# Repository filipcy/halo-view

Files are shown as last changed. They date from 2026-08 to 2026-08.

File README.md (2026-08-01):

# HALO View

HALO View is a wall-mounted home interface designed around architecture, not around a tablet.

It transforms a Samsung Galaxy Tab A11 (SM-X130) into a permanent, calm and serviceable element of the interior. Home Assistant is the backend; HALO is the product experience.

## Current status

- Product: HALO View
- Hardware target: Samsung Galaxy Tab A11 SM-X130
- Orientation: portrait
- Hardware stage: Rev A / engineering definition
- Software stage: existing Home Assistant dashboard as MVP

## V1 objective

Mount the tablet without drilling, hide the cable, preserve easy service access and make the device look as if it belonged in the room from the beginning.

## Core principle

> HALO should never look like a tablet mounted on a wall.

## Repository map

- `docs/` — product definition, principles, requirements and decisions
- `cad/` — source models, exports, prototypes and references
- `hardware/` — dock, faceplate, USB routing, materials and BOM
- `ui/` — future HALO interface assets and Home Assistant implementation
- `project/` — epics, user stories and templates
- `manufacturing/` — print and production documentation

Start with [`docs/00_VISION.md`](docs/00_VISION.md).

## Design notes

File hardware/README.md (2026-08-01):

# Hardware

Product-specific engineering documentation:

- `dock/`
- `faceplate/`
- `usb/`
- `materials/`
- `bom/`

CAD source remains under `cad/`; this area stores requirements, selection notes and released hardware documentation.

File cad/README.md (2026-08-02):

# CAD

HALO View mechanical source, review records, and controlled manufacturing exports live here.

## Structure

- `source/` — editable source models and generators
- `reviews/` — iteration review notes and review graphics
- `exports/` — neutral STEP exports
- `stl/` — released print meshes
- `prototypes/` — fit-test and Rev A sections
- `references/` — validated reference geometry

## HALO Dock Rev A

Iteration 2 is generated by [`source/HALO_Dock_Rev_A.py`](source/HALO_Dock_Rev_A.py). It retains the `TabletEnvelope`, split `Faceplate`, `DockBody`, `WallInterface`, and `Assembly` structure, then adds parameter-driven side guides, a lower shelf, non-final upper side-detent studies, and hidden flat mounting fields. The top insertion path stays open. The WallInterface fields physically establish the 1.5 mm shadow gap, and the generator validates the nominal 18 mm wall-to-front stack.

See [`reviews/HALO_Dock_Rev_A_Iteration_2.md`](reviews/HALO_Dock_Rev_A_Iteration_2.md) and its [review schematic](reviews/HALO_Dock_Rev_A_Iteration_2.svg) for scope, exclusions, projection math, and release gates. The [Iteration 1 review](reviews/HALO_Dock_Rev_A_Iteration_1.md) remains the accepted baseline record.

Released files must use controlled part names and revision identifiers. Generator output is a working artifact until its review gates are closed and it is explicitly copied into a release directory.

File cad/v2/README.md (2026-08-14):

# HALO wall mount V2 — design review package

V2 preserves the physically selected Rev A tablet envelope and sliding fit:
125 × 211 × 8 mm, R8.5 corners, 0.20 mm X/Y clearance and 0.30 mm depth
clearance per face. The old 18 mm enclosure stack is replaced by a slim rear
skeleton directly against the wall. The 11 mm dimension is explicitly measured
from the wall-contact plane (Z=0) to the actual front surface of the 8 mm tablet
(Z=3+8), not to a clearance-envelope or printed-retainer face.

The physically validated 8.6 mm Rev A pocket-depth assumption remains recorded
as `VALIDATED_POCKET_DEPTH`, but it is not used as a printable V2 forward
extent. Guides and shelves occupy the real tablet envelope from Z=3.0 to
Z=11.0 mm. The true maximum Z across every generated holder solid is 11.0 mm.

The tablet rear datum remains Z=3.0 mm, but the tablet-facing rear skeleton ends
at Z=2.7 mm. These are deliberately separate concepts: the resulting physical
rear clearance is 0.30 mm without moving the tablet or increasing projection.

The top is open. A split 3 mm bottom shelf carries the tablet; 1.25 mm side lips
prevent forward release while leaving the Samsung bezel dominant. The right
button opening retains its 46 mm span and is moved from 146–192 mm to 124–170 mm
from the bottom datum: exactly 22 mm lower.

The 0.8 mm-thick side retainers occupy Z=10.2–11.0 mm, within the front-most
portion of the tablet thickness envelope. Their front faces are flush with the
actual tablet front at Z=11.0 mm; no retainer material projects in front of it.
Their 1.25 mm XY capture and open-top insertion path are unchanged.

The 22 × 30 mm 90-degree USB-C pocket and 12 mm route are review envelopes, not
a released or production-approved cable fit. Both remain configurable and the
selected adapter, housing and bend radius must be measured before print release.
The route is an opening in the skeleton leading to a wall exit behind
the tablet, so it does not add to global projection.

The camera relief is on the physical **left when the SM-X130 is viewed from the
rear**. Because model X is defined while looking at the front, this is the +X
(right in front view) side. This intentionally fixes the mirrored Rev A relief.

The exposed upper and lower plan edges use a subtle 2 mm chamfer. It is confined
to the exterior outline: the tablet pocket, 0.20 mm side clearance, 1.25 mm
retainers and the Z=11 mm tablet-front plane are unchanged.

## Regenerate

```bash
python3 cad/source/HALO_Wall_Mount_V2.py
```

The command writes the review STL and eight SVG views here. The STL consists of
overlapping closed solids intended to be unioned by the slicer; a native Fusion
rebuild and interference check remain required before manufacturing.

## FDM orientation

Print with the broad rear skeleton on the build plate (wall face down). This
keeps the visible guide walls vertical and avoids supports in the tablet pocket.
Use 0.2 mm layers, at least four perimeters, and bridge the 1.25 mm retention
lips. A brim is preferable to sanding the visible sides.

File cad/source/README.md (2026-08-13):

# HALO Dock Rev A source

`HALO_Dock_Rev_A.py` is the native Fusion 360 parametric source generator. Sprint 3 retains accepted Iteration 2 full-part geometry and adds test coupons, measured Dual Lock recess logic, and gated exports. Static Python checks are not native CAD validation.

## Native validation setup and rerun safety

Every validation run must start in a **fresh, empty Hybrid Design** document. The generator creates multiple internal components, which Fusion does not permit in a Part Design document. If Fusion reports that Part Design documents can contain only one component, open or convert the document to Hybrid Design and begin again in a fresh empty document.

A failed run can leave partial generated components behind. The generator is not transactional and deliberately does not delete existing components, because they may be unrelated user work. Do not rerun it in the document left by a failed validation; discard that document and repeat the validation in another fresh empty Hybrid Design.

## Export modes

`EXPORT_MODE` defaults to `COUPONS_ONLY` and writes controlled STEP + STL pairs for coupon parts to `~/Documents/HALO_Dock_Rev_A/coupons/`. It never exports full Faceplate/DockBody meshes or assembly F3D/STEP/PNG. The 0.2/0.3/0.4 mm clearance gauges, open L corner/lip coupon, and full-pocket-width guide/shelf coupon are included. The separately named left and right single-field wall articles are included only after a valid physical Dual Lock measurement; no STL contains loose wall-coupon bodies.

`FULL_SIZE_PRINT_CANDIDATE` writes to `~/Documents/HALO_Dock_Rev_A/print-candidate/`, but only after the measured wall stack and every explicit evidence flag passes. Flags cover native execution, +1 mm rebuild, interference checks, coupon approval, clearance selection, slicer review, and written authorization. Full parts remain `PRINT CANDIDATE ONLY`. Full mode emits separate component-scoped STEP + STL pairs for Faceplate and DockBody; it never exports the contaminated design root.

The generator finishes each full-size printable component with native Fusion
Combine/Join features. Full-size release validation blocks export unless both
`Faceplate.bRepBodies.count` and `DockBody.bRepBodies.count` equal exactly one.
After changing or pulling this generator, rerun it natively in Fusion 360 from a
fresh, empty Hybrid Design document and repeat the timeline, interference, STEP,
STL, and slicer inspections; static tests cannot prove native BRep joins.

## Measurement blocker

`dual_lock_measured_engaged_thickness` defaults to `0 mm`, meaning **NOT MEASURED**. It is labeled `REQUIRED PHYSICAL MEASUREMENT — exact selected Dual Lock pair`. Do not substitute a catalog claim or estimate. The wall coupon and all full-size exports remain blocked until the exact selected, mated pair is measured and the derived recess leaves positive structural backing.

Follow `cad/reviews/HALO_Dock_Rev_A_Sprint_3.md`. No Fusion execution, export, slicer review, or physical validation was performed in this repository environment.

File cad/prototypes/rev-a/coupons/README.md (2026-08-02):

# Rev A coupon artifacts

This directory is a controlled landing area, **not a release**. The source of the geometry is `cad/source/HALO_Dock_Rev_A.py`. Do not add hand-made or renamed CAD/mesh/image files.

Artifact states are sequential:

1. **source generator** — committed Python only;
2. **generated, unverified** — produced by a native Fusion run but not accepted;
3. **native-verified** — rebuild, symmetry, section, and interference checks recorded;
4. **slicer-verified** — opened at 100%, dimensions/orientation/walls/supports/manifold/build volume checked;
5. **released coupon** — written approval links the evidence and exact file checksum.

Only verified native exports may be placed here. No artifact is currently committed or released.

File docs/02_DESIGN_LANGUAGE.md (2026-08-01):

# Design Language

## Character

HALO is calm, architectural, precise and unobtrusive. It should feel closer to a built-in control panel than to consumer electronics attached after construction.

## Physical language

- Portrait orientation follows the vertical rhythm of the hallway: doors, mirror, tiles and wooden slats.
- Outer corner geometry should visually continue the Samsung tablet rather than surround it with a separate decorative frame.
- The faceplate should be visually thin, with softened or chamfered visible edges.
- A controlled shadow gap should make the product feel light without appearing detached from the wall.
- Visible screws, brackets and adhesive edges are not acceptable.
- The V1 finish is matte black or very dark charcoal, compatible with the existing black interior details.

## Digital language — future direction

- The interface belongs to the room, not to Android or Home Assistant.
- Use restrained colour; colour communicates state or required attention.
- Prefer clear outcomes and actions over raw sensor values.
- Motion should be subtle, direct and without decorative bounce.
- The screen should spend more time quiet or asleep than demanding attention.

## Tone of voice — future direction

Prefer:

- `Dom jest gotowy.`
- `Możesz spokojnie wyjść.`
- `Jedna rzecz wymaga uwagi.`

Avoid:

- technical entity names;
- diagnostic jargon on the primary screen;
- excessive success messages;
- generic smart-home marketing language.

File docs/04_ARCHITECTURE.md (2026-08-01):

# Hardware Architecture

## Components

### HALO Dock

The wall-side structure responsible for:

- adhesive mounting interface;
- structural stiffness;
- alignment;
- cable routing and connector relief;
- controlled wall offset;
- service access.

### HALO Faceplate

The visible product surface responsible for:

- visually integrating the tablet;
- continuing the tablet corner language;
- retaining the tablet without loading the display;
- hiding mechanical interfaces;
- allowing tool-free service access.

### Tablet

Samsung Galaxy Tab A11 SM-X130, bare, portrait orientation. The tablet is not an adhesive mounting surface and should not carry structural loads from the wall interface.

## Assembly concept

```text
Faceplate / carrier
        │
     Tablet
        │
      Dock
        │
  3M Dual Lock
        │
      Tile
```

## Engineering rules

- Model from a central datum and symmetric reference geometry where practical.
- Tablet contact should occur on safe enclosure surfaces, not through pressure on the active display area.
- Allow manufacturing and tablet tolerances; do not use catalogue dimensions as exact fit dimensions without validation.
- Protect the USB-C connector from bending load.
- Hide service openings from normal viewing angles.
- Prefer geometry that prints without visible support damage on exterior surfaces.

## Expansion reserve

V1 may reserve internal routing volume for a future small indicator or ambient-light module. Any reserve must remain invisible, must not increase V1 complexity materially and must not compromise stiffness or printability.

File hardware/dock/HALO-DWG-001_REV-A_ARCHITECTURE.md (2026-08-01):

# HALO-DWG-001 — Dock Rev A Architecture

**Document status:** Design freeze candidate  
**Product:** HALO View  
**Device:** Samsung Galaxy Tab A11 SM-X130  
**Orientation:** Portrait  
**Date:** 2026-08-01

## Purpose

This document freezes the mechanical architecture inputs required to begin the first parametric CAD model. It is not a manufacturing release drawing.

## Product stack

From wall to user:

1. tiled wall;
2. 3M Dual Lock adhesive interface;
3. wall-side Dock;
4. tablet pocket and cable service volume;
5. bare SM-X130 tablet;
6. visible matte Faceplate.

## Accepted Rev A parameters

| Parameter | Rev A value | Release status |
|---|---:|---|
| Tablet orientation | portrait | fixed |
| Tablet insertion direction | from top | fixed |
| Visible bezel | 6.0 mm | fixed |
| Inner screen lip | 0.5 mm target | verify against active display |
| Display recess from Faceplate plane | 0.8 mm | fixed for Rev A |
| Tablet pocket clearance | +0.3 mm per side | prototype assumption |
| Wall shadow gap | 1.5 mm | fixed for Rev A |
| Total projection from tile | approximately 18 mm | packaging target |
| Wall mounting | 3M Dual Lock only | fixed |
| Visible finish | matte black / near-black charcoal | fixed |
| Visible screws | none | fixed |
| Cable exit | bottom, downward | fixed |
| Cable type | standard USB-C envelope preferred | validate during CAD |

## Functional architecture

### Dock

The Dock carries structural loads, provides the wall interface, controls the shadow gap and contains the cable service volume. The adhesive side of the Dual Lock remains attached to the tile during normal tablet service.

### Faceplate

The Faceplate controls the visible geometry, screen recess, edge language and tablet retention. It must not clamp the active glass or require visible fasteners.

### Tablet insertion

The tablet enters from the top, follows side guides and lands on a positive lower datum. Retention must prevent forward movement and rattle while allowing deliberate removal without tools.

### Cable path

The cable connects at the bottom edge near the confirmed 59 mm horizontal datum from the left device edge. The service volume must avoid side-loading the USB-C port and must allow the cable to leave vertically downward. Final chamber geometry remains blocked by cable-envelope validation.

## CAD parameters to expose

The source CAD must expose at least:

- device width, height and thickness;
- device corner profile;
- bezel width;
- inner lip overlap;
- screen recess;
- pocket clearance X/Y/Z;
- front thickness;
- wall shadow gap;
- total projection target;
- Dual Lock pad size and position;
- USB port datum and connector envelope;
- lower support thickness;
- retention feature clearance;
- camera, speaker, microphone and button keep-out zones.

## Open engineering decisions

The following are deliberately not yet frozen:

1. Faceplate structural thickness.
2. Exact outer corner spline/radius after geometric reconstruction.
3. Outer-edge fillet/chamfer treatment.
4. Retention geometry at the top.
5. Exact standard cable and bend envelope.
6. Dual Lock field size and spacing.
7. Print material and manufacturing orientation.

## Rev A review criteria

The first CAD review must show:

- front, rear and side orthographic views;
- section through the screen edge;
- section through the bottom USB service volume;
- exploded view of Dock, tablet and Faceplate;
- wall interface and 1.5 mm shadow gap;
- tablet insertion and removal path;
- proposed print orientation and support strategy.

## Release gate

No full-size print is released until:

- the open dimensions are resolved or explicitly accepted as prototype assumptions;
- a fit coupon validates the +0.3 mm pocket clearance and screen-edge geometry;
- the cable chamber is validated against a physical cable;
- the Product Owner approves the rendered front and side proportions.

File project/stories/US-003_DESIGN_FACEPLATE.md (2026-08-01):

# US-003 — Design the HALO Faceplate

**Epic:** EPIC-001  
**Status:** TODO

## User story

As a homeowner, I want the mounted tablet to read as a purpose-built architectural panel, so that it belongs visually in the hallway.

## Description

Design the visible tablet carrier and Faceplate with proportions, corner transitions and finish consistent with the Samsung device and the target interior. Retention must be safe, quiet and serviceable.

The accepted Rev A visual parameters are:

- visible bezel width: 6.0 mm;
- inner screen lip target: 0.5 mm;
- tablet pocket clearance: +0.3 mm per side;
- portrait orientation;
- matte black or near-black charcoal finish.

Front thickness, final corner geometry and edge treatment remain engineering parameters. They must be selected to balance stiffness, print quality, tactile quality and visual lightness.

## Acceptance criteria

- [ ] Visible bezel is 6.0 mm around the tablet, except for any explicitly approved functional deviation.
- [ ] Inner edge overlap target is 0.5 mm and remains outside the active display area.
- [ ] Outer corner language visually follows the tablet rather than introducing an unrelated radius.
- [ ] Faceplate does not press structural load onto the display glass.
- [ ] Tablet pocket begins with +0.3 mm clearance per side and is parameterised for prototype adjustment.
- [ ] Tablet does not rattle or move during normal touch interaction.
- [ ] Required controls, microphones and speakers remain functional.
- [ ] No screws, retention clips or service gaps are visible from normal viewing positions.
- [ ] Exterior surfaces are suitable for a premium matte finish.
- [ ] Faceplate can be removed for service without detaching the wall-side Dual Lock mounting interface.

## Tests

1. Compare a full-scale 6 mm outline/render with the physical tablet both on and off.
2. Verify the 0.5 mm lip against all active-display and gesture areas.
3. Insert and remove the tablet twenty times without scratches or damaged retention features.
4. Operate the full touch surface and hardware controls.
5. Check speaker and microphone performance for obvious obstruction.
6. Inspect at close range, two metres and in the mirror under hallway lighting.
7. Apply normal one-finger touch loads and confirm no visible movement or rattle.

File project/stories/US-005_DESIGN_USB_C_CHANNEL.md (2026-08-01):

# US-005 — Design the USB-C channel

**Epic:** EPIC-001  
**Status:** TODO

## User story

As a homeowner, I want the charging cable to be invisible and mechanically protected, so that HALO View looks permanent and the tablet charges reliably.

## Description

Design the bottom USB-C service chamber and cable path for a low-profile 90-degree connector. The chamber must protect the tablet port from side load and allow cable installation and replacement without redesigning the visible Faceplate.

The connector envelope remains open until a specific cable is selected and measured.

## Acceptance criteria

- [ ] USB-C remains connected without bending or side-loading the tablet port.
- [ ] No cable is visible from normal front and side viewing positions.
- [ ] The cable exits downward toward the wall route.
- [ ] Speaker and microphone openings are not materially obstructed.
- [ ] The connector chamber is parameterised around a measured cable envelope.
- [ ] The cable can be replaced during service without destroying the Dock or Faceplate.
- [ ] The channel does not create a visibly thicker lower bezel without explicit approval.

## Tests

1. Install the selected cable and verify charging for at least eight continuous hours.
2. Apply light cable movement below the panel and confirm no load reaches the tablet port.
3. Inspect the mounted assembly from the front, both sides and in the hallway mirror.
4. Remove and reinstall the cable five times without damage.
5. Play audio and confirm no obvious speaker blockage.

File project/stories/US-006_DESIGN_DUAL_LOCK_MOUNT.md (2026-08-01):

# US-006 — Design the Dual Lock wall mount

**Epic:** EPIC-001  
**Status:** TODO

## User story

As a homeowner, I want HALO View mounted securely to tile without drilling, so that the installation is reversible and visually clean.

## Description

Design the wall-side Dock interface for 3M Dual Lock SJ3550 or a validated equivalent. The mounting fields must hold the complete assembly during normal use while still allowing deliberate service removal.

No screws, wall plugs or permanent mechanical fixings are permitted in V1.

## Acceptance criteria

- [ ] Assembly mounts to clean tile using only the approved reclosable fastener.
- [ ] Mounting fields are hidden in normal use.
- [ ] Panel remains level and does not rotate during touch interaction.
- [ ] Dock can be deliberately removed without tools and without pulling on the tablet.
- [ ] Faceplate/tablet service does not require removing the wall-side adhesive interface.
- [ ] Mounting geometry allows accurate levelling before final pressure is applied.
- [ ] The design documents tile preparation, adhesive cure time and removal method.
- [ ] Mounting reserve is appropriate for the measured assembly mass and touch loads.

## Tests

1. Mount a representative mass to a test surface using the intended Dual Lock area and preparation method.
2. Leave mounted for seven days and inspect for creep, rotation or partial release.
3. Apply repeated normal touch loads at screen corners.
4. Remove and reconnect the mechanical Dual Lock interface ten times.
5. Verify that service access does not disturb adhesive bonded to the tile.

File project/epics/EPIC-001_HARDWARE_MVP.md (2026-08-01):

# EPIC-001 — HALO View Hardware MVP

**Status:** IN PROGRESS

## Objective

Deliver a premium, wall-mounted and serviceable HALO View for the Samsung Galaxy Tab A11 SM-X130, ready for installation and real-world testing.

## Scope

- Validated tablet and cable measurements.
- HALO Dock Rev A.
- HALO Faceplate Rev A.
- No-drill Dual Lock mounting.
- Protected and visually concealed USB-C routing.
- Prototype, print release, installation and seven-day test.

## Out of scope

- LED hardware.
- HALO-native UI.
- E-paper companion.
- Support for other tablets.

## User stories

- [ ] US-001 — Capture production measurements
- [ ] US-002 — Design the HALO Dock
- [ ] US-003 — Design the HALO Faceplate
- [ ] US-004 — Validate prototype fit and installation

## Definition of Done

- Full-size printed assembly is installed on the target tiled wall.
- Tablet is stable during normal touch interaction.
- Cable and mounting system are not visible from normal viewing positions.
- Tablet can be removed and reinstalled without damage.
- Seven-day field test completes without loosening, deformation or thermal concern.
- Product Owner accepts appearance and function.

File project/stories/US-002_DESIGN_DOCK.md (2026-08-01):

# US-002 — Design the HALO Dock

**Epic:** EPIC-001  
**Status:** TODO

## User story

As a homeowner, I want a rigid no-drill wall dock, so that HALO View remains stable, removable and visually clean.

## Description

Design the wall-side structure that transfers load to the tile through Dual Lock, establishes the shadow gap, aligns the visible assembly and protects the charging cable.

## Acceptance criteria

- [ ] Dock supports portrait installation on flat tile.
- [ ] Dual Lock contact areas are defined and accessible during installation.
- [ ] Normal touch interaction does not cause visible rocking.
- [ ] Cable chamber prevents bending load on the USB-C port.
- [ ] Dock remains hidden from normal front and oblique viewing positions.
- [ ] Design is printable by a commercial FDM service without damage to visible surfaces.

## Tests

1. Apply repeated touch loads at all four display corners; assembly remains stable.
2. Remove and refit the service assembly ten times; interfaces remain functional.
3. Inspect from front, both sides and through the hallway mirror; Dock is not visually intrusive.

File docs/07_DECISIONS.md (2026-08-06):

# Decision Log

## ADR-001 — Dedicated tablet fit

**Status:** Accepted

HALO View V1 is designed specifically for the bare Samsung Galaxy Tab A11 SM-X130. Universal compatibility would weaken proportions, retention and finish quality.

## ADR-002 — Portrait orientation

**Status:** Accepted

Portrait orientation follows the vertical architectural rhythm of the target hallway and avoids the kiosk/browser layout issues observed in landscape mode.

## ADR-003 — Two-part architecture

**Status:** Accepted

The product consists of a wall-side Dock and visible Faceplate/tablet carrier. The Dock handles mounting, stiffness and cable routing; the Faceplate handles fit, service and appearance.

## ADR-004 — No drilling

**Status:** Accepted

V1 mounts to tile using a removable high-strength reclosable fastener, currently 3M Dual Lock SJ3550 or validated equivalent. Screws, wall plugs and permanent mechanical fixings are out of scope.

## ADR-005 — USB-C from bottom using a standard cable envelope

**Status:** Accepted

Charging enters at the tablet's bottom edge and is routed through a protected service chamber. V1 must not require a proprietary or unusually specific cable. A standard straight USB-C cable is the default design basis unless physical packaging proves unacceptable; a low-profile angled cable remains an allowed optimisation, not a product requirement.

## ADR-006 — Matte dark finish

**Status:** Accepted

The visible hardware uses matte black or near-black charcoal to join the apartment's existing black details and remain visually quiet against grey tile and wood.

## ADR-007 — Future lighting provision only

**Status:** Accepted

V1 contains no LED hardware. A small invisible routing or packaging reserve may be included only when it does not delay, weaken or visibly compromise V1.

## ADR-008 — Quality over schedule

**Status:** Accepted

The desired two-day print-release target is subordinate to fit, safety, manufacturability and visual approval.

## ADR-009 — Faceplate bezel width: 6 mm

**Status:** Accepted  
**Date:** 2026-08-01

The visible Faceplate bezel is fixed at **6 mm**. A 7 mm alternative was visually reviewed with the tablet both on and off and was rejected because it appeared heavier and more visually dominant.

### Rationale

- 6 mm preserves the intended architectural-panel presence without reading as an added protective case.
- It gives the display a better screen-to-product proportion.
- It integrates more quietly with the grey tile, oak slats and mirror.
- It retains enough material for stiffness and a controlled internal screen lip.

### Consequences

- The active CAD parameter for bezel width is 6.0 mm.
- The internal edge may overlap the glass by 0.5 mm, subject to active-display verification.
- Any later change to bezel width requires a new visual review and an explicit superseding decision.

## ADR-010 — Initial body clearance: +0.3 mm per side

**Status:** Accepted for Rev A validation  
**Date:** 2026-08-01

The initial tablet pocket uses a nominal clearance of **+0.3 mm per side**. This value is a prototype assumption and must be validated with a fit coupon or first prototype before production release.

**Superseded for X/Y fit by ADR-017.** The 0.3 mm Z clearance and the complete 0.2/0.3/0.4 mm coupon set remain unchanged.

## ADR-011 — V1 scope remains hardware-only

**Status:** Accepted  
**Date:** 2026-08-01

Current work is limited to the HALO Dock V1 mechanical product: Faceplate, Dock, USB-C routing and Dual Lock mounting. Lighting, e-paper, custom electronics and HALO UI development remain backlog items and may not delay the mechanical MVP.

## ADR-012 — Tablet inserts from the top

**Status:** Accepted  
**Date:** 2026-08-01

The tablet is inserted vertically from the top. Gravity assists retention, the bottom edge can provide a positive mechanical datum, and routine service does not require flexing the visible Faceplate.

## ADR-013 — Display recess: 0.8 mm

**Status:** Accepted for Rev A  
**Date:** 2026-08-01

The display surface is recessed approximately **0.8 mm** behind the visible Faceplate plane. This creates a controlled shadow line, protects the glass edge and avoids a visually flat case-like appearance. The Faceplate must not press on the active display surface.

## ADR-014 — Wall shadow gap: 1.5 mm

**Status:** Accepted for Rev A  
**Date:** 2026-08-01

The visible assembly uses a nominal **1.5 mm** shadow gap to the wall datum. The gap must remain visually even and must not expose Dual Lock, cable routing or service features from normal viewing positions.

## ADR-015 — Total wall projection target: 18 mm

**Status:** Accepted as Rev A packaging target  
**Date:** 2026-08-01

The complete installed product targets approximately **18 mm total projection from the tile surface to the front Faceplate plane**. This is a packaging target, not an absolute release limit. It may be revised only if cable bend radius, structural stiffness or serviceability cannot be achieved without compromising quality.

## ADR-016 — Visible finish is matte

**Status:** Accepted  
**Date:** 2026-08-01

The visible Faceplate finish is fully matte rather than satin or gloss. Material, print orientation and finishing method must minimise layer glare, fingerprints and reflections in the hallway mirror.

## ADR-017 — Coupon-validated tablet fit and USB-C relief

**Status:** Accepted for Rev A physical fit correction

**Date:** 2026-08-06

Physical coupon validation selects **0.20 mm per side in X and Y** and an **8.5 mm device corner radius**. The 0.2/0.3/0.4 mm clearance coupons and R8/R8.5/R9 corner coupons remain controlled records and must not be removed.

The accepted lower-shelf width, top datum, and 3.0 mm functional height remain fixed. The 3.0 mm hidden structural-thickness parameter directly drives joined internal root gussets contained within the accepted shelf and side-guide outlines. The USB-C pocket gains 0.30 mm only downward and 0.20 mm only toward the rear/depth; its edge-derived horizontal datum and 18 mm width remain unchanged. The shelf continues to carry the tablet so a standard straight USB-C connector carries no tablet load. Release gates remain in force.

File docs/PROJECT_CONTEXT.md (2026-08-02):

# HALO Project Context

> Source of Truth for the HALO project.
> Read this document before making any design, CAD or software decision.

---

# Vision

HALO is not a tablet holder.

HALO is an architectural wall-mounted smart home interface.

The goal is to make the tablet appear as if it was designed as part of the apartment.

Long term the project may evolve into:

- custom hardware
- dedicated OS
- custom dashboard
- e-paper companion display
- status LED
- commercial product

---

# Product Philosophy

Quality > Time

Every design decision must improve at least one of:

- aesthetics
- usability
- manufacturability
- reliability

Never add features because they are possible.

Only solve real problems.

---

# Design Language

Inspired by:

- Apple
- Sonos
- Basalte

Characteristics:

- minimal
- timeless
- hidden mounting
- invisible cable
- soft radii
- matte finish
- architectural object

---

# Current Hardware

Device:

Samsung Galaxy Tab A11 SM-X130

Current assumptions:

- bezel 6 mm
- screen lip 0.5 mm
- screen recess 0.8 mm
- total projection ≈18 mm
- wall shadow gap 1.5 mm
- PETG
- matte black

Wall mounting:

3M Dual Lock only.

No screws.

No visible fasteners.

---

# Development Process

GitHub is the source of truth.

Workflow:

Issue
↓

Codex implementation
↓

Pull Request
↓

Review
↓

Merge
↓

Next Sprint

Never merge without review.

---

# Completed Work

## Sprint 1

Repository foundation

CAD architecture

Parametric generator

Faceplate

Tablet envelope

DockBody foundation

Merged

---

## Sprint 2

Mechanical geometry

Side guides

Lower shelf

Retention concept

Dual Lock concept

Shadow gap

Merged

---

## Sprint 3

External print candidate

Status:

IN PROGRESS

Goals:

- manufacturing package
- fit coupons
- vendor documentation
- first printable prototype

---

# Printing Strategy

No in-house printer.

All parts are printed by an external company.

Always validate using coupons before ordering full-size parts.

---

# Long Term Roadmap

Phase 1

Perfect Dock

↓

Phase 2

Electronics

↓

Phase 3

LED status

↓

Phase 4

e-paper companion

↓

Phase 5

Custom Dashboard

↓

Phase 6

HALO OS

↓

Phase 7

Commercial Product

---

# Definition of Done

A sprint is complete only when:

- PR reviewed
- merged
- documentation updated
- GitHub clean
- manufacturing impact assessed

---

# Golden Rule

If a decision improves appearance but hurts usability:

don't do it.

If a decision improves engineering but hurts appearance:

think twice.

HALO must always feel like architecture, not electronics.

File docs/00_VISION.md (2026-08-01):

# HALO Vision

## Product vision

HALO is an architectural interface between a person and their home.

It should feel like it has always belonged in the room. Technology remains quiet and mostly invisible until the user needs it.

## Problem

Most smart-home dashboards expose entities, states and controls. They make the user interpret data instead of helping manage the home.

HALO should reduce cognitive load by presenting meaningful status, attention items and actions. The underlying entities remain available, but they are not the primary experience.

## V1 focus

The first release is intentionally narrow: a premium wall-mounted interface based on the Samsung Galaxy Tab A11 SM-X130.

V1 proves that the physical product can:

- integrate visually with the interior;
- mount without drilling;
- conceal and protect the charging connection;
- remain removable and serviceable;
- support the existing Home Assistant dashboard immediately.

## North-star statements

- HALO should never look like a tablet mounted on a wall.
- The room defines the product, not the device.
- Technology should disappear until it is needed.
- Hardware and software form one experience.
- Decisions and actions matter more than entities.
- Quality is more important than schedule.

## Long-term direction

Future releases may introduce HALO UI, contextual insights, ambient signalling and companion e-paper hardware. These are not part of V1 and must not delay it.

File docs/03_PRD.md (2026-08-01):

# Product Requirements Document

## Product

HALO View V1

## User problem

The user has a useful Home Assistant control centre but no permanent, visually integrated access point. Using a phone or desktop adds friction, while a conventional tablet mount would look temporary and expose cabling.

## Target user

A technically capable homeowner who values both home automation and interior design, and wants an always-available interface that feels native to the apartment.

## V1 outcome

A Samsung Galaxy Tab A11 SM-X130 is mounted vertically on tiled wall without drilling, remains powered, can be removed for service and looks like a purpose-built architectural panel.

## Functional requirements

- Dedicated fit for a bare SM-X130 tablet.
- Portrait orientation.
- USB-C connection accessible from the bottom of the tablet.
- Two-part product architecture: wall dock and visible faceplate/tablet carrier.
- Tool-free normal tablet removal.
- Mounting through removable high-strength adhesive fastener such as 3M Dual Lock.
- No visible screws or conventional tablet-holder arms.
- Charging cable routed without damaging or loading the USB-C connector.
- Existing Home Assistant dashboard usable immediately through Fully Kiosk.

## Quality requirements

- No tablet movement or rattle during normal touch interaction.
- No pressure points on the display glass.
- No obstruction of required buttons, speakers, microphones, camera or charging port.
- No sharp edges touching the tablet.
- Surface finish appropriate for permanent display in a finished interior.
- Geometry must be manufacturable by a professional 3D-printing service.

## Success criteria

- The installed object reads as a dedicated panel from normal hallway viewing distance.
- Cable is not visible from the primary approach direction.
- Tablet can be removed and reinstalled without wall damage.
- Mount remains stable through repeated touch use.
- Prototype survives a seven-day installed trial without loosening, deformation or thermal concern.

## Non-goals for V1

- LED or ambient lighting hardware.
- E-paper companion.
- Custom Android operating system or launcher.
- New HALO-native dashboard.
- Universal support for other tablets.
- Wireless charging.
- Integrated environmental sensors.

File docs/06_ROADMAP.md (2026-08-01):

# Roadmap

## V1 — Hardware MVP

Goal: install a finished-looking, serviceable HALO View using the existing Home Assistant dashboard.

- Freeze measurements and cable choice.
- Produce Dock Rev A and Faceplate Rev A CAD.
- Print fit-test sections before full-size production.
- Release printable files and manufacturing notes.
- Install with Dual Lock on tile.
- Complete seven-day field test.

## V1.1 — Refinement

- Correct fit and tolerance findings.
- Improve surface finish and assembly ergonomics.
- Finalise installation template and documentation.

## V2 candidates

- HALO-native interface and design system.
- Contextual home-management insights.
- Reserved ambient-status light module.
- HALO Paper e-paper companion.

V2 candidates do not alter the V1 release gate.

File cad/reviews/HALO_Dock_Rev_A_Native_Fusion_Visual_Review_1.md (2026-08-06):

# HALO Dock Rev A — Native Fusion visual review 1

**Review status:** Corrections required; full-size manufacture blocked

## Native run and exports

The HALO Dock generator completed successfully in native Fusion 360, including recomputation and timeline checks. The controlled coupon STEP and STL exports also completed successfully. These results validate generator execution and coupon export mechanics only; they do not authorize full-size manufacture.

## Visual findings and source disposition

1. **Lower shelf — failed visual review.** The first reinforced model exposed circular lobes below the DockBody outline. The source correction replaces those lobes with joined internal rectangular gussets whose width is bounded by `dock_side_wall` and whose height is bounded by the accepted 3.0 mm shelf height. They remain inside the existing shelf/guide overlap, below or coincident with the seating plane, and do not project in front of the established guide depth. The validated shelf width, shelf height, seating plane, speaker opening, and USB opening are unchanged.
2. **Rear cable route — confirmation required on rerun.** The L-shaped rear-view form is generated by `CutFeatureOperation`, from the tablet-side XY datum through `-dock_back_thickness`; it is a recessed, bottom-open cable channel rather than an added body. It cannot increase the 18 mm installed projection. Source guards retain the edge-derived USB-C position, 18 mm width, 0.30 mm downward relief, and 0.20 mm rear/depth relief, and reject overlap with the speaker, camera, or button keep-outs. A corrected native rear-view section must confirm the intended open channel visually.
3. **WallInterface — intentionally measurement-gated, not redesigned.** The accepted architecture remains two discrete Dual Lock fields with a 1.5 mm shadow gap. Because `dual_lock_measured_engaged_thickness` remains 0 mm, the wall coupons and measured rear recesses are intentionally deferred/omitted. Once the exact mated pair is selected and measured, the existing implementation derives its recess depth and preserves installed projection. No new mounting architecture is introduced by this correction.

## Gate

Full-size Faceplate and DockBody manufacture remains blocked. Rerun the corrected generator in native Fusion 360, inspect front/bottom/rear sections for hidden gusset containment and an open recessed cable route, re-run interference checks, and record verified full-size exports before changing any release gate.

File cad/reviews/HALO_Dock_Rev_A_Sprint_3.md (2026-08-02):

# HALO Dock Rev A — Sprint 3 CAD review checklist

**Status: source ready for native validation; no generated artifact or print release**

## Coupon review

- The guide/shelf coupon has an inner rail spacing of `device_width + 2 × coupon_guide_clearance`; at current temporary device input and selected 0.3 mm clearance that expression evaluates nominally to 125.6 mm. This is an unevaluated CAD input, not an inspected print dimension. Its joined 30 mm rails are open at the top and overlap a connected shelf whose seating area spans the whole pocket, allowing the real tablet to descend vertically and fully seat.
- `Coupon_Faceplate_Open_Corner_L` uses a single open L profile, with top and side arms joined by concentric outer and inner arcs. The outer arc is `device_corner_radius + bezel_width`; each inner arc is derived from its lip/skirt band so neither layer has a square corner that can collide with the real tablet. It includes separate visible lip and rear-skirt layers. There is no nested profile or closed ring around the device; the tablet extends freely beyond both arm ends.
- Clearance coupons are connected U-shaped process/slot gauges at 0.2, 0.3, and 0.4 mm per side; their rails overlap and join a parametric base rather than exporting as loose bodies.
- Both separately exported, single-solid left/right wall articles are omitted while `dual_lock_measured_engaged_thickness == 0 mm`. **BLOCKED — exact Dual Lock pair must be selected and measured before print release.**

## Dual Lock section intent

`wall_shadow_gap` remains the visible 1.5 mm perimeter gap. Once an exact mated pair is measured, `dual_lock_recess_depth = dual_lock_measured_engaged_thickness - wall_shadow_gap`. Two symmetric, discrete rear pockets receive any measured excess; each real pad stack terminates on its pocket floor, forming wall → Dual Lock → DockBody contact. The generator rejects negative recess, through-depth recess, asymmetric fields, and non-positive remaining backing. Open space remains around and between fields; there is no printable full-area spacer.

The generator preserves a non-zero `dual_lock_measured_engaged_thickness` already entered in Fusion when rerun; it must not reset physical evidence to the source default. A measured thickness exactly equal to the shadow gap is valid and produces a zero-depth recess without asking Fusion to create an invalid zero-distance cut.

## Mandatory native Fusion 360 and slicer checklist

1. Open an empty **parametric** Fusion Design.
2. Run the generator with `EXPORT_MODE = COUPONS_ONLY`.
3. Confirm there are no exceptions; record the Fusion version and run log.
4. Inspect every named parameter and identify measured, verified, temporary, and placeholder values.
5. Change `device_width` from 125 to 126 mm and `device_height` from 211 to 212 mm.
6. Rebuild and record the result.
7. Verify left/right symmetry for side guides, retention, fit rails, guide-coupon rails, Dual Lock fields, and wall-coupon fields.
8. Restore 125 × 211 mm and rebuild.
9. Run interference/path checks: TabletEnvelope vs Faceplate; TabletEnvelope vs DockBody; vertical tablet insertion path; Dual Lock recess vs DockBody.
10. Capture section views of Faceplate lip, guide + shelf, and wall stack.
11. Export controlled STEP + STL pairs for every coupon Part ID (the separate left/right wall articles only after entering the physical measurement). Confirm no output contains loose bodies.
12. Open every STL in the intended slicer at exactly 100% scale.
13. Check and record bounding dimensions, orientation, thin walls, supports, manifold geometry, and build volume.
14. Save screenshots, logs, slicer project/version, file hashes, and pass/fail results.
15. Confirm full-size mode exports only component-scoped Faceplate and DockBody STEP + STL pairs, with no root STEP or reference/coupon contamination. Only after coupon manufacture and written approval consider `FULL_SIZE_PRINT_CANDIDATE`; separately satisfy every in-source gate and obtain written authorization.

Fusion 360 and a slicer are unavailable in this development environment. Native execution, rebuild, interference/path analysis, actual export, mesh inspection, and physical testing have **not** been performed.

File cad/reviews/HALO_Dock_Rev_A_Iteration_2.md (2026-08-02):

# HALO Dock Rev A — Iteration 2 review

**Date:** 2026-08-01  
**Status:** Parametric mechanical layout review; not a print release  
**Device:** Samsung Galaxy Tab A11 SM-X130, portrait

## Review intent

Iteration 2 turns the accepted Iteration 1 package into a parameter-driven mechanical fit study. It adds paired side guides, a lower support shelf, a deliberately non-final upper side-detent concept, and two hidden flat 3M Dual Lock mounting fields. The portrait top edge has no crossbar or overhanging feature, so the top insertion path remains fully open.

## Generated geometry

| Component | Iteration 2 content | Manufacturing status |
|---|---|---|
| `TabletEnvelope` | 125 × 211 × 8 mm rounded reference envelope | Reference only; measurements require validation |
| `Faceplate` | Existing split front lip and rear perimeter skirt | Fit/visual study only |
| `DockBody` | Projection-controlled backing, paired side guides, lower shelf, and paired upper side-detent studies | Mechanical layout only |
| `WallInterface` | Two 25 × 50 mm flat fields spanning the 1.5 mm wall separation | Mounting concept only; 3M stack/specification unvalidated |
| `Assembly` | Named placeholder | Joints and service motion deferred |

Every new size and location is controlled by a named Fusion user parameter or an expression derived from one. Side guides start outside `device_width / 2 + pocket_clearance_x`; the shelf starts below `-device_height / 2 - pocket_clearance_y`; and the side detent concept occupies only the side-clearance band. These construction rules prevent new solid geometry from entering `TabletEnvelope` at nominal values.

## Open insertion and retention concept

The two guides terminate below the tablet's top edge, and no geometry spans between them. The tablet therefore retains a fully open, straight top insertion path. The small paired features near the upper sides are named **NOT FINAL** in the Fusion timeline and bodies. They record only a possible side-detent location; they are not a released latch, do not close the top, and require insertion-force, tolerance, wear, and accessibility studies.

## Wall stack, shadow gap, and projection check

The wall datum is modeled at `-dock_back_thickness - wall_shadow_gap`. The flat mounting-field bodies start on that plane and span the 1.5 mm separation to the DockBody rear face. This makes `wall_shadow_gap` physical geometry rather than documentation alone.

The nominal installed projection is checked by the generator before body creation:

`wall_shadow_gap + dock_back_thickness + device_thickness + screen_recess`

With the current parameter expressions this is `1.5 + 7.7 + 8.0 + 0.8 = 18.0 mm`. `dock_back_thickness` is derived from `total_projection_target`, so changes to the target or other stack elements rebuild the rear depth. This is a packaging check, not an installed-product measurement.

## Explicitly out of scope

Iteration 2 does **not** include:

- USB-C routing, connector/service volume, or cable exit geometry;
- a final latch, spring selection, snap validation, or assembly motion;
- final fillets, chamfers, texture, edge breaks, or cosmetic finishing;
- camera, speaker, microphone, or button relief geometry;
- a released 3M Dual Lock part number, adhesive stack, installation template, or load rating.

## Review and release gates

1. Native Fusion 360 execution, parametric rebuild, body-to-body interference inspection, and generated F3D/STEP/STL/PNG exports must pass before physical release.
2. Verify TabletEnvelope dimensions and corner radius by caliper and coupon, then inspect guide, shelf, and detent clearance across tolerance extremes.
3. Demonstrate an unobstructed top insertion sweep in Fusion and with a physical fit article.
4. Confirm the actual wall, Dual Lock product, engaged thickness, field size, edge offsets, installation load, and removal access.
5. Measure installed wall-to-front projection; the CAD target is 18.0 mm, but the approximately 18 mm requirement remains unverified physically.
6. Develop USB routing and final retention in later iterations without consuming TabletEnvelope or the open insertion path.

## Environment verification status

Fusion 360 is unavailable in the development environment used for this change. Native execution, rebuild testing, interference checks, and generated exports therefore remain **unverified**. Static Python compilation and repository text checks do not replace these release gates.

**Decision:** Accept for Iteration 2 CAD review only. Do not release, install, or merge on the strength of static checks alone.

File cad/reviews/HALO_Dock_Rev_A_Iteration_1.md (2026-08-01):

# HALO Dock Rev A — Iteration 1 review

**Date:** 2026-08-01  
**Status:** Parametric layout review; not a print release  
**Device:** Samsung Galaxy Tab A11 SM-X130, portrait

## Review intent

Iteration 1 establishes the controlling Fusion 360 parameters and validates the basic visual/packaging relationship among the tablet envelope, visible Faceplate, and preliminary DockBody. The generator creates all five architecture component names: `TabletEnvelope`, `Faceplate`, `DockBody`, `WallInterface`, and `Assembly`.

Only the first three contain geometry. `WallInterface` and `Assembly` are explicit placeholders so deferred work is not mistaken for released geometry.

## Generated geometry

| Component | Iteration 1 content | Manufacturing status |
|---|---|---|
| TabletEnvelope | 125 × 211 × 8 mm rounded reference envelope, nominal 18 mm corners | Reference only; measurements require validation |
| Faceplate | Rounded frame with 6 mm external bezel, 0.5 mm screen lip, 0.8 mm visible front lip depth and rear perimeter skirt outside the tablet envelope | Visual/fit review only |
| DockBody | 3 mm planar rounded backing sized from the cleared tablet envelope and 3 mm perimeter allowance | Packaging review only |
| WallInterface | Empty named placeholder | Deferred |
| Assembly | Empty named placeholder | Deferred |

The tablet display plane is at the front of the nominal 8 mm tablet envelope. The Faceplate is split into two parameter-driven solids in one component:

- the visible front lip starts at `device_thickness` and extrudes forward by `screen_recess`, placing the finished Faceplate plane exactly 0.8 mm ahead of the display plane at 8.8 mm;
- the rear perimeter skirt starts at `device_thickness + screen_recess - front_thickness` (6.4 mm with the current values) and extrudes only by `front_thickness - screen_recess` to the tablet display datum at 8.0 mm.

The rear skirt opening is expanded by the pocket clearances, so the skirt remains outside `TabletEnvelope` instead of occupying the tablet volume. The DockBody extrudes 3 mm rearward from the tablet rear datum. The accepted 1.5 mm wall shadow gap and approximately 18 mm projection remain exposed parameters; the wall interface required to realize them is not modeled in this iteration.

## Scope exclusions

Iteration 1 intentionally has **no**:

- USB-C routing, connector chamber, or bottom cable exit geometry;
- top latch or other retention geometry;
- side guides;
- lower support shelf;
- 3M Dual Lock fields or adhesive placement geometry;
- final outer-edge fillets, chamfers, or cosmetic finishing;
- assembly joints, motion study, or insertion-path geometry;
- camera, speaker, microphone, or button relief geometry.

The corresponding cable, mounting, clearance, and keep-out parameters are present to preserve design intent, but placeholders must not be treated as validated measurements.

## Automated deliverables

Running the script in Fusion 360 automatically creates `~/Documents/HALO_Dock_Rev_A_Iteration_1/` and exports:

- the full design as F3D;
- the full design as STEP;
- separate Faceplate and DockBody STL meshes at high refinement; and
- a 1920 × 1080 active-viewport PNG.

These are working exports, not controlled release artifacts.

## Print orientation and support assumption

For early FDM layout checks, orient the **Faceplate front face down** on a clean, smooth build plate and the **DockBody wall-side face down**. The current planar forms are intended to print **without supports** in those orientations. TabletEnvelope, WallInterface, and Assembly must not be included as print parts.

This assumption must be reviewed when retention, shelf, cable routing, and wall features are introduced. Cosmetic face quality, elephant-foot compensation, material, shrinkage, and minimum wall performance have not yet been validated.

## Review findings and gates

1. Sketch dimensions, construction-plane offsets, and extrusion extents reference the Fusion user-parameter expressions directly; the confirmed USB horizontal datum is 59 mm from the left device edge, while cable-envelope and keep-out assumptions remain provisional.
2. The generator validates the Iteration 1 layer stack before creating geometry: the rear skirt must stop at the tablet display datum, the visible lip must preserve `screen_recess`, and pocket clearances must be non-negative so rear Faceplate material stays outside `TabletEnvelope`.
3. The Faceplate establishes the intended architectural outline, but active-display and gesture clearance must verify the 0.5 mm overlap.
4. The DockBody demonstrates only the rear packaging footprint; stability and wall attachment cannot yet be assessed.
5. Caliper measurements, a corner-radius coupon, and a physical fit coupon are required before full-size printing.
6. The selected low-profile USB-C cable must be measured before any connector/service volume is released.
7. Iteration 2 should add validated fit features and sections without prematurely freezing cosmetic edge finishing.

**Decision:** Accept Iteration 1 as a parametric CAD baseline only. Do not release for installation or full-size manufacture.

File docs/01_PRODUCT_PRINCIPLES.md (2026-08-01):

# Product Principles

1. **Quality over time** — no part is released until its purpose and execution are accepted.
2. **MVP is not minimum effort** — V1 is narrow in scope but complete in appearance and function.
3. **Interior first** — the wall, light, materials and viewing angles are part of the product.
4. **Calm technology** — HALO should not compete for attention.
5. **Action over information** — show what matters and what can be done, not raw entity state.
6. **One-second comprehension** — the primary state should be understandable at a glance.
7. **Serviceable by design** — the tablet must be removable without damaging it or the wall.
8. **No visible compromise** — future expansion provisions must not make V1 look unfinished.
9. **Every visible line has a purpose** — geometry, gaps and transitions must be intentional.
10. **Build less, design more** — new features enter only when they improve the user experience.

## Scope discipline

Ideas such as ambient lighting, e-paper, HALO UI and intelligence are retained as future opportunities. They do not enter V1 unless required to make the core hardware viable.

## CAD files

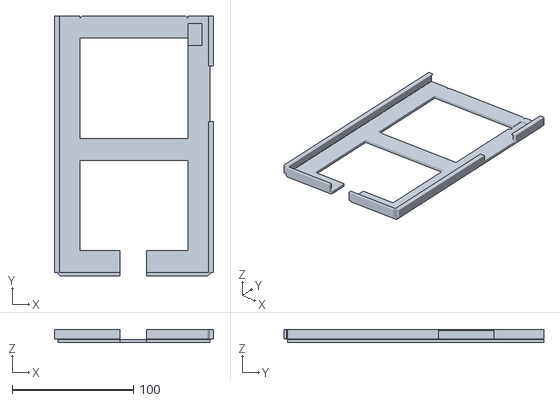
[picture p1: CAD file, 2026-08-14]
cad/v2/HALO_Wall_Mount_V2_review.stl
131.4 x 214.4 x 11.0

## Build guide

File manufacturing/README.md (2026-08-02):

# Manufacturing

Sprint 3 manufacturing documentation is in `HALO_Dock_Rev_A_External_Print_Candidate/`. It is an execution package under development, not a manufacturing release. The repository currently contains no native-generated CAD/mesh artifacts.

Coupon-first policy is mandatory. Full-size Faceplate and DockBody remain **PRINT CANDIDATE ONLY**, require separate written authorization, and must not be quoted or printed until all documented gates pass.

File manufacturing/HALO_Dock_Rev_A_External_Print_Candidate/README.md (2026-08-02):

# HALO Dock Rev A — external print-candidate package

**Release state: NOT READY FOR EXTERNAL PRINT. Full-size printing is prohibited until coupon approval and separate written authorization.**

The generator defaults to `COUPONS_ONLY`. It produces five currently eligible coupon Part IDs as matched STEP + STL pairs (three clearance gauges, an open L Faceplate corner, and a full-width guide/shelf test) under `~/Documents/HALO_Dock_Rev_A/coupons/`. The separately named left/right single-field wall articles are conditionally omitted because the exact selected Dual Lock pair has not been measured.

`FULL_SIZE_PRINT_CANDIDATE` is a consciously selected, fail-closed mode. It requires native Fusion execution, a 125→126 mm width and 211→212 mm height rebuild, interference/path checks, coupon approval, selected clearance, physical Dual Lock measurement, slicer review, and written full-size authorization. Its output is isolated under `~/Documents/HALO_Dock_Rev_A/print-candidate/` as separate Faceplate and DockBody STEP + STL pairs. No root-design STEP is exported because reference and coupon components must not contaminate vendor geometry.

**BLOCKED — exact Dual Lock pair must be selected and measured before print release.** `0 mm` explicitly means not measured. The intended design retains a 1.5 mm visible open shadow gap and pockets only measured excess thickness into two symmetric, discrete DockBody recesses. Dual Lock bonds to the pocket floors so the load path is wall → Dual Lock → DockBody; no full-area spacer may fill the gap.

## Vendor controls

- Never scale: import and print at **100%**.
- Do not run automatic mesh repair, healing, wall thickening, hole closing, or orientation changes without written approval.
- Support-free printing is a requirement pending native/slicer confirmation; report any perceived need for supports instead of adding them.
- Material is PETG, matte black, pending final vendor/process approval.
- Quote coupons separately. Do not quote or print full-size parts without explicit written authorization identifying checksums.

No native Fusion run, actual export, slicer review, or physical test has been performed in this environment. Use the CAD checklist and receiving inspection; static checks cannot release parts.

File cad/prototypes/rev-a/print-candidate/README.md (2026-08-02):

# Rev A full-size print-candidate artifacts

This directory is a controlled landing area and is currently empty. **No full-size part is released for printing.** Full exports may be placed here only after coupon approval, all native Fusion and slicer gates, exact Dual Lock pair measurement, and separate written authorization.

The source generator, generated-but-unverified, native-verified, slicer-verified, and released-print-candidate states are distinct. Never commit a fabricated, manually renamed, or non-native F3D/STEP/STL/PNG. Record checksums and evidence before changing state.

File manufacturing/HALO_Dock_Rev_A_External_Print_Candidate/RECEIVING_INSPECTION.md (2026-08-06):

# Receiving inspection

Quarantine parts until inspection is recorded. Never scale or automatically repair a received/re-exported file to make it pass.

1. Match package, Part ID, revision, quantity, paired STEP/STL filenames, and checksums to the authorized RFQ.
2. Confirm vendor process/material/finish statement and 100% scale; record actual bounding dimensions against the **verified exported** values (currently TBD).
3. Inspect warpage, cracks, layer separation, incomplete/thin walls, support scars (supports are not authorized), sharp debris, and front-surface damage.
4. Run each clearance gauge on the real bare tablet without force; record pass/fail and measured/observed behavior before selecting clearance.
5. Insert the real tablet vertically into the guide/shelf coupon from the open top. Confirm both rails remain parallel, do not clamp, preserve the selected clearance, and allow the whole lower edge to seat on the full pocket-width shelf.
6. Apply the open Faceplate L to the matching real corner, leaving the tablet outside the two open arm ends. Inspect screen-lip coverage, recess, pocket clearance, skirt engagement, actual radius, top/side bezel, and visible face quality. A closed-ring or obstructed coupon is nonconforming.
7. Wall articles: **BLOCKED until exact pair measurement.** Receive the separately named left and right single-solid articles; reject a file containing two loose bodies. Verify equivalent discrete recesses, flat bond faces, real samples contacting pocket floors, a 1.5 mm visible-gap witness, and no continuous shadow-gap filler.
8. Photograph, measure, and disposition every nonconformance. No physical coupon result releases a full-size print automatically.
9. For the corrected USB-C pocket, verify the accepted edge-based horizontal datum and 18 mm width, plus 0.30 mm added downward and 0.20 mm added rear/depth relief using the selected straight cable. Confirm the tablet seats on the shelf with no load transferred to the connector.
10. Inspect the accepted-width, 3.0 mm-high lower shelf and its hidden internal root gussets for complete material, cracks, or layer separation. Reject exposed material outside the DockBody outline; do not grind or thin the tablet seating surface.

Full Faceplate/DockBody parts require a separate receiving plan tied to written full-size authorization; they are not currently orderable.

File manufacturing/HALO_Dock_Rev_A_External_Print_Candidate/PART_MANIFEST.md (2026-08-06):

# Part manifest — Rev A Sprint 3

All bounding dimensions are `TBD AFTER VERIFIED EXPORT`; no native export exists to inspect. Every printable Part ID must be delivered as a matching `.step` + `.stl` pair with identical revision and geometry scope. Quantity means one test article when its gate is released, not order authorization.

| Part ID / controlled files | Rev | Qty | Status | Nominal bounding dimensions | Material | Required orientation | Supports | Purpose | Release gate |
|---|---:|---:|---|---|---|---|---|---|---|
| `HALO_Dock_Rev_A_Clearance_0_2mm.step` + `HALO_Dock_Rev_A_Clearance_0_2mm.stl` | A | 1 | SOURCE ONLY; coupon candidate | TBD AFTER VERIFIED EXPORT | PETG matte black, pending vendor confirmation | As verified in slicer; preserve generated axes | None required, pending slicer review | 0.2 mm-per-side process/fit slot gauge | Native paired export + 100% slicer verification + written coupon authorization |
| `HALO_Dock_Rev_A_Clearance_0_3mm.step` + `HALO_Dock_Rev_A_Clearance_0_3mm.stl` | A | 1 | SOURCE ONLY; coupon candidate | TBD AFTER VERIFIED EXPORT | same | same | None required, pending review | 0.3 mm-per-side nominal gauge | same |
| `HALO_Dock_Rev_A_Clearance_0_4mm.step` + `HALO_Dock_Rev_A_Clearance_0_4mm.stl` | A | 1 | SOURCE ONLY; coupon candidate | TBD AFTER VERIFIED EXPORT | same | same | None required, pending review | 0.4 mm-per-side gauge | same |
| `HALO_Dock_Rev_A_Faceplate_Open_Corner_L_R8_0.step` + `HALO_Dock_Rev_A_Faceplate_Open_Corner_L_R8_0.stl` | A | 1 | SOURCE ONLY; 8.0 mm radius coupon candidate | 52 × 52 mm XY; Z TBD AFTER VERIFIED EXPORT | same | Front visible surface down, subject to slicer verification | None required, pending review | Apply open top/right L arms to a real tablet corner; inspect 8.0 mm radius, bezel/lip coverage, recess, pocket clearance, skirt, and front finish | Native one-BRep/manifold review + paired export/slicer verification + written coupon authorization |
| `HALO_Dock_Rev_A_Faceplate_Open_Corner_L_R8_5.step` + `HALO_Dock_Rev_A_Faceplate_Open_Corner_L_R8_5.stl` | A | 1 | SOURCE ONLY; 8.5 mm radius coupon candidate | 52 × 52 mm XY; Z TBD AFTER VERIFIED EXPORT | same | Front visible surface down, subject to slicer verification | None required, pending review | Apply open top/right L arms to a real tablet corner; inspect 8.5 mm radius, bezel/lip coverage, recess, pocket clearance, skirt, and front finish | Native one-BRep/manifold review + paired export/slicer verification + written coupon authorization |
| `HALO_Dock_Rev_A_Faceplate_Open_Corner_L_R9_0.step` + `HALO_Dock_Rev_A_Faceplate_Open_Corner_L_R9_0.stl` | A | 1 | SOURCE ONLY; 9.0 mm radius coupon candidate | 52 × 52 mm XY; Z TBD AFTER VERIFIED EXPORT | same | Front visible surface down, subject to slicer verification | None required, pending review | Apply open top/right L arms to a real tablet corner; inspect 9.0 mm radius, bezel/lip coverage, recess, pocket clearance, skirt, and front finish | Native one-BRep/manifold review + paired export/slicer verification + written coupon authorization |
| `HALO_Dock_Rev_A_Side_Guide_Lower_Shelf.step` + `HALO_Dock_Rev_A_Side_Guide_Lower_Shelf.stl` | A | 1 | SOURCE ONLY; coupon candidate | TBD AFTER VERIFIED EXPORT | same | Shelf/rail support-free orientation as verified in slicer | None required, pending review | Insert real tablet vertically; verify rail parallelism, selected clearance, no clamping, and full seating | Native rebuild/path review + paired export/slicer verification + written coupon authorization |
| `HALO_Dock_Rev_A_Faceplate_USB_C_Cable_Pocket.step` + `HALO_Dock_Rev_A_Faceplate_USB_C_Cable_Pocket.stl` | A | 1 | SOURCE ONLY; cable coupon candidate | TBD AFTER VERIFIED EXPORT | same | Visible lip down, subject to native/slicer verification | None required, pending review | Use the real tablet and USB-C cable to verify insertion, connector-housing clearance, bend freedom, and no rear-skirt contact | Native one-BRep/interference review + paired export/slicer verification + written coupon authorization |
| `HALO_Dock_Rev_A_Wall_Stack_Shadow_Gap_Right.step` + `HALO_Dock_Rev_A_Wall_Stack_Shadow_Gap_Right.stl` | A | 1 | **BLOCKED — Dual Lock NOT MEASURED** | TBD AFTER VERIFIED EXPORT | same plus exact selected Dual Lock sample | Wall-side mounting face per verified section | None required, pending review | Right single-field wall-stack article; inspect recess, flatness, gap witness, and pad-to-floor contact | Exact pair measurement + native section + paired export/slicer verification + written authorization |
| `HALO_Dock_Rev_A_Wall_Stack_Shadow_Gap_Left.step` + `HALO_Dock_Rev_A_Wall_Stack_Shadow_Gap_Left.stl` | A | 1 | **BLOCKED — Dual Lock NOT MEASURED** | TBD AFTER VERIFIED EXPORT | same plus exact selected Dual Lock sample | same | None required, pending review | Left single-field counterpart; compare against right article and recorded symmetry | same |
| `HALO_Dock_Rev_A_Faceplate_PRINT_CANDIDATE_ONLY.step` + `HALO_Dock_Rev_A_Faceplate_PRINT_CANDIDATE_ONLY.stl` | A | 1 | PRINT CANDIDATE ONLY; **PROHIBITED** | TBD AFTER VERIFIED EXPORT | same | Front face down, pending verification | None required, pending review | Full Faceplate prototype; component-only vendor files | All source gates + coupon approval + separate written full-size authorization |
| `HALO_Dock_Rev_A_DockBody_PRINT_CANDIDATE_ONLY.step` + `HALO_Dock_Rev_A_DockBody_PRINT_CANDIDATE_ONLY.stl` | A | 1 | PRINT CANDIDATE ONLY; **PROHIBITED** | TBD AFTER VERIFIED EXPORT | same | Wall-side face down, pending verification | None required, pending review | Full DockBody prototype; component-only vendor files | All source gates + coupon approval + separate written full-size authorization |

There is deliberately no full-design/root STEP. `TabletEnvelope`, coupons, `WallInterface` reference solids, and `Assembly` placeholder content are prohibited from full-size vendor files.

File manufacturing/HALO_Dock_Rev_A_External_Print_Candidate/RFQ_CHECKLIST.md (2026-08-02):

# RFQ checklist

## Before sending any coupon RFQ

- [ ] Native Fusion run and parameter audit recorded.
- [ ] +1 mm width/height rebuild and symmetry checks passed.
- [ ] Each Part ID has matching STEP + STL filenames and SHA-256 values recorded against the manifest.
- [ ] STL inspected at 100% for bounding box, orientation, thin walls, supports, manifold state, and build volume.
- [ ] Vendor instructed: 100% scale; no automatic repair/healing; no geometry, wall, orientation, or support changes without written approval.
- [ ] PETG matte black and finish/process are explicitly confirmed rather than inferred.
- [ ] Quote identifies every coupon separately and excludes full-size parts.

## Functional coupon instructions

- Guide/shelf: use the real bare tablet; lower it vertically through the fully open top between both shortened rails until the complete lower edge seats on the shelf. Record entry force, free clearance/no clamp, rail parallelism, full-width seating, rocking, and removal.
- Faceplate: place the open L on the matching real tablet corner with the rest of the tablet projecting freely beyond both arm ends. Inspect actual outer radius, top/side bezel, screen-lip coverage, screen recess, pocket clearance, rear skirt, and visible front finish. Reject any export that behaves as a closed ring.
- Clearance gauges: test all three without forcing; select clearance only from recorded physical results.
- Wall stack: do not request until the exact selected mated Dual Lock pair is measured. The left and right fields are separate controlled Part IDs, never loose bodies in one file. Bond a real sample flat into each recess; verify the 1.5 mm open shadow-gap witness, direct pad-to-pocket-floor contact, and left/right equivalence.

## Full-size exclusion

- [ ] RFQ states: **FULL-SIZE PRINTING PROHIBITED until coupon approval and separate written authorization.**
- [ ] No Faceplate or DockBody mesh is attached to a coupon RFQ.
- [ ] No root-design STEP is supplied; full-size vendor files, if separately authorized later, are component-scoped Faceplate and DockBody STEP + STL pairs only.

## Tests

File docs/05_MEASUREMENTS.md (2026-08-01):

# Measurements

## Device

Samsung Galaxy Tab A11 SM-X130, bare tablet.

## Measurement policy

Catalogue dimensions are reference only. Rev A may use carefully captured manual measurements and photographs, but print release must clearly identify every value that still requires validation against the physical device or selected cable.

## Captured device measurements

| Feature | Value | Method | Confidence |
|---|---:|---|---|
| Overall width | 125 mm | traced outline and tape measure | medium |
| Overall height | 211 mm | traced outline and tape measure | medium |
| Maximum thickness | 8 mm | direct ruler/tape comparison | medium |
| Corner radius/profile | approximately 18 mm | traced outline and visual estimate | low–medium |
| USB-C opening width | approximately 8 mm | direct tape/ruler comparison | medium |
| USB-C opening height | approximately 2 mm | visual/manual measurement | low–medium |
| USB-C opening lower offset | approximately 1 mm from lower edge | visual/manual measurement | low |
| USB-C lateral location | reported as 5.9 mm reference measurement | manual measurement; datum requires confirmation | low |
| Buttons | right-hand long edge | photo reference | high |
| Speaker openings | present on short edge around USB-C | photo reference | high |
| Microphone openings | visible near short/long edges | photo reference | medium |
| Rear camera | upper-left rear corner | photo reference | high |
| Camera protrusion | small; exact value TBD | side/rear photo | low |

## Important USB-C clarification

The reported **5.9 mm** USB-C value is retained as captured input, but its datum is not yet unambiguous enough for production CAD. Before the connector pocket is released, it must be confirmed whether 5.9 mm describes:

- distance from a nearby edge to the beginning of the opening;
- distance to the opening centre;
- or another local reference.

The selected low-profile 90-degree cable must also be measured before its service chamber is frozen.

## Visual references captured

The reference set includes:

- traced front outline;
- front and rear orthographic photographs;
- bottom-edge USB-C and speaker photographs;
- long-edge button photograph;
- side profile confirming a substantially flat back;
- earlier photographs with a Polish 2 grosze coin as a scale reference.

## Rev A tolerance targets

These are prototype assumptions, not production-release values:

- tablet pocket clearance: **+0.30 mm per side**;
- non-cosmetic sliding clearance: 0.30–0.50 mm;
- visible Faceplate bezel: **6.00 mm**;
- inner screen lip/overlap target: **0.50 mm**, subject to active-display verification;
- display glass must not carry structural clamping load;
- USB connector chamber: open parameter until the exact cable is selected and measured.

## Measurements still required before full print release

1. Exact body dimensions with a caliper or validated manufacturer drawing.
2. Exact corner profile, preferably using a printed radius gauge or fit coupon.
3. Unambiguous USB-C X/Y datums.
4. Exact selected 90-degree connector envelope and cable exit direction.
5. Camera protrusion and required rear relief.
6. Confirmation that the 0.5 mm lip remains outside the active display and does not obstruct gestures.

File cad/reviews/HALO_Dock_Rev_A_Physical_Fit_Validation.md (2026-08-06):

# HALO Dock Rev A — physical fit validation correction

**Date:** 2026-08-06

**Status:** Fit selections recorded; full-size release remains gated

## Accepted observations

- The physical clearance series selects 0.20 mm per side for the tablet pocket in X and Y. All 0.2, 0.3, and 0.4 mm coupon definitions and manufacturing records remain available.
- The physical corner series selects an 8.5 mm device corner radius. R8, R8.5, and R9 coupons remain available as traceable validation articles.
- The accepted lower-shelf width (`device_width + 2 * pocket_clearance_x`), top datum, and 3.0 mm functional height are preserved. The 3.0 mm hidden structural-thickness parameter drives joined internal gussets contained entirely within the existing shelf/guide overlap and DockBody outline.
- Connector fit requires 0.30 mm additional downward relief and 0.20 mm additional rear/depth relief. The edge-based horizontal centre and 18 mm pocket width are unchanged.

## Load path and cable constraint

The tablet must seat on the continuous lower shelf around the connector opening. Verify a visible/feeler clearance between the seated tablet and the straight USB-C connector body so the connector carries no tablet load. A 90-degree connector is neither required nor the design basis.

## Physical revalidation checklist

1. Reprint the selected 0.20 mm and R8.5 articles alongside retained comparison coupons; confirm free insertion without clamp or corner rocking.
2. Seat the tablet on the lower shelf and confirm the shelf, not the connector, establishes the vertical datum.
3. Connect the selected straight USB-C cable and inspect the added downward and rear clearance, bend freedom, and absence of housing contact.
4. Confirm the camera keep-out, right button relief, lower speaker opening, USB-C horizontal alignment, and USB-C pocket width against the source parameters.
5. Record native Fusion rebuild, interference review, paired STEP/STL checksums, slicer orientation, and photographs before any authorization.

Coupon approval does not authorize full-size manufacture. Dual Lock measurement, native timeline health, export verification, and every existing release gate remain open until separately signed off.

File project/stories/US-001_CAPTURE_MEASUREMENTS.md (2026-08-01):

# US-001 — Capture production measurements

**Epic:** EPIC-001  
**Status:** TODO

## User story

As a product team, we want validated physical measurements of the tablet and selected charging cable, so that the first prototype is based on reliable geometry.

## Description

Measure the bare Samsung Galaxy Tab A11 SM-X130 and the selected low-profile 90-degree USB-C connector. Record the device envelope, corner geometry, connector position, controls, openings and clearances required for safe retention.

## Acceptance criteria

- [ ] Width, height and maximum thickness are recorded with measurement method.
- [ ] USB-C position and selected connector envelope are recorded.
- [ ] Buttons, camera, speakers and microphones have documented keep-out zones.
- [ ] Measurements are entered in `docs/05_MEASUREMENTS.md`.
- [ ] Uncertain values are clearly marked and not silently assumed.

## Tests

1. Repeat each critical measurement three times; spread must be acceptable for the selected tolerance.
2. Compare the recorded envelope with a physical paper or simple CAD template.
3. Confirm the selected cable can connect without forced bending.

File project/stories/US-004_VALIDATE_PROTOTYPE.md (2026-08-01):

# US-004 — Validate prototype fit and installation

**Epic:** EPIC-001  
**Status:** TODO

## User story

As a Product Owner, I want the prototype validated before final installation, so that only a safe, functional and visually accepted design is released.

## Description

Use low-cost section prints where useful, followed by the full Rev A assembly. Validate fit, cable relief, assembly, wall positioning, finish and real-world stability before accepting V1.

## Acceptance criteria

- [ ] Critical corner, retention and USB geometry is validated before or during Rev A.
- [ ] Full assembly installs without drilling.
- [ ] Cable is concealed from normal viewing positions.
- [ ] Tablet is removable without tools or damage.
- [ ] Assembly remains stable during normal interaction.
- [ ] Product Owner approves installed appearance.
- [ ] Seven-day field test is completed and findings documented.

## Tests

1. Complete fit inspection against the actual tablet and cable.
2. Perform repeated touch interaction at the centre and corners.
3. Remove and reinstall the tablet after wall installation.
4. Inspect the assembly in daytime, hallway lighting and mirror reflection.
5. Record temperature, loosening, noise, deformation and cable issues during seven days.

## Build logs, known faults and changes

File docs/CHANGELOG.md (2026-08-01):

# Changelog

## 2026-08-01 — Foundation

- Named the product HALO View.
- Defined the architectural product vision and V1 scope.
- Selected Samsung Galaxy Tab A11 SM-X130 as the dedicated hardware target.
- Accepted portrait orientation, two-part Dock/Faceplate architecture, no-drill mounting and bottom USB-C routing.
- Created product principles, PRD, design language, architecture, roadmap, measurement plan and decision log.
- Created EPIC-001 and the initial V1 user stories.

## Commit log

2026-08-01 structure: add CAD workspace
2026-08-01 docs(decisions): freeze HALO Dock V1 bezel and mounting decisions
2026-08-01 docs(backlog): add Dual Lock mounting story
2026-08-01 cad: add DockBody and Iteration 1 review
2026-08-01 fix(cad): link Rev A geometry to parameters
2026-08-01 fix(cad): prevent faceplate tablet interference
2026-08-01 docs(cad): describe split faceplate stack
2026-08-01 docs(cad): update faceplate layer-stack review
2026-08-01 docs(cad): revise faceplate layer-stack schematic
2026-08-01 cad: add HALO Dock Rev A Iteration 2 geometry
2026-08-02 fix(cad): correct Fusion rectangle profile construction
2026-08-02 Add PROJECT_CONTEXT.md for HALO project documentation
    This document outlines the vision, product philosophy, design language, current hardware, development process, completed work, printing strategy, long-term roadmap, definition of done, and a golden r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
2026-08-02 cad: gate Sprint 3 coupon-first print package
2026-08-02 fix(cad): make Sprint 3 coupons native-safe
2026-08-02 fix(cad): isolate controlled STEP and STL exports
2026-08-02 fix(cad): make nested Fusion profiles deterministic
2026-08-02 fix(cad): use one concentric profile anchor
2026-08-02 fix(cad): center nested profiles independently
2026-08-02 fix(cad): rebuild open corner coupon as joined solid
2026-08-02 fix(cad): remove overlapping corner datums
2026-08-02 fix(cad): remove redundant corner constraints
2026-08-02 fix(cad): use positive corner arc sweeps
2026-08-02 fix(cad): add SM-X130 fit candidates and keep-outs
2026-08-02 fix(cad): complete rounded USB-C cable clearance
2026-08-02 fix(cad): cut speaker slot through lower shelf
2026-08-02 fix(cad): constrain rounded cable envelope profile
2026-08-02 fix(cad): validate recomputed cable envelope BRep
2026-08-02 fix(cad): use temporary rectangular cable envelope
2026-08-02 fix(cad): validate coupon solids without cable envelope
2026-08-02 fix(cad): rebuild clearance coupons as slotted solids
2026-08-02 fix(cad): extrude clearance coupons from U profiles
2026-08-02 fix(cad): validate clearance coupon functional geometry
2026-08-06 fix(cad): apply coupon-validated physical fit
2026-08-06 fix(cad): keep shelf reinforcement below seat
2026-08-06 fix(cad): offset Fusion shelf reinforcement diameter dimension
2026-08-06 fix(cad): hide shelf gussets after Fusion review
2026-08-06 fix(cad): increase internal USB-C flex clearance
2026-08-06 Unify Fusion printable component bodies
2026-08-13 Correct V2 camera relief and edge treatment
    [HALO_Wall_Mount_V2_review.stl]
2026-08-13 Keep V2 retainers behind tablet front
    [HALO_Wall_Mount_V2_review.stl]
2026-08-14 Constrain all V2 geometry to tablet front
    [HALO_Wall_Mount_V2_review.stl]
2026-08-14 Restore V2 rear tablet clearance
    [HALO_Wall_Mount_V2_review.stl]
2026-08-14 Add provisional USB-C cable routing
2026-08-14 Simplify USB cable retention bridge
2026-08-17 Guard cable opening against residual geometry
